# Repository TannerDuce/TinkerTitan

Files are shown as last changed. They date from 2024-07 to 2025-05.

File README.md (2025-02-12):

Tinker Titan V1

New documentation Here --> https://docs.google.com/document/d/1ggTJ-sIj0q-C6EPkmgzcmBBHiNBAO2c4_2ZdBtOWOQ4/edit?tab=t.0

The following set of instructions is outdated, left for reference

Here we will give some basic instructions on how to set up your Tinker Titan, Start to Finish.

**1. Board Assembly:**

Start by soldering the provided connectors onto the main PCB. Depending on how your doing this program, you may also have to
install the surface mount parts yourself, or all of the components will come pre-installed on the circuit board.note that the
2x3 connector in the center of the board is intentionally left blank, as it is the ISP header used to burn the first files
onto the Atmel chip. <-(more on this later)                               .


Next, we solder the motor wires onto the end of the motor. each wire should measure approximately 5.5" long. The wires 
can be cut as short as 5", but a little extra is always good. additionally, tin the opposite ends of the wires. this will 
make it easier to get them into the terminal blocks.
motorwirelength

Next, we will fit the motors into the main chassis. Note that there is a tab on the chassis where the motor lies, which
helps to hold it in place. if the motor is set in upside-down, it simply will not fit in all the way and will need 
to be flipped around. Once the motors are in place, use #4 hardware to secure them, as shown below. Once they are in
place, the cables must be routed along the central channel to provide space for the battery to be set in place on top of them

motorinstalation

Next up is the battery. once you have assembled the battery pack, insert it into the chassis as shown. make sure the
switch on the battery pack is turned on, as it will no longer be accessible. instead of using the switch, the Tinker 
Titan was designed just to be unplugged to power it off.
batterypackinstalation

Once the battery pack is in place, install the cover plate. use #4 hardware to secure it to the chassis.
20240626_125109(0)

Using the machined stand-offs, mount the circuit board to the top of the cover plate as shown below:


Next, wire up your motors into the terminal blocks at the bottom. Don't worry about polarity yet, as long as the 2 wires
from the left motor go to the left terminal block, and the same for the right. (we will correct this later) Try plugging
it in to ensure the battery pack is on. The green light should stay on, solid.



Next, we will assemble the tracks. using the hardware from the back the tracks come in, place the nut in the front slot.
take the short bolt and after placing the wheel on the bolt, add a washer and fasten it to the chassis. for the driven
wheel, find the wheel with the keyed D shaft, and fit it onto the motor. once both are in place, stretch the track over
the two sprockets. do this for both sides of the robot:


Now that the base model is complete, we will add the sensor assembly. this gives the robot the ability to compete in the
sumo challenge and do things such as line following. start by clipping the Ultrasonic sensor into the piece with
the dovetail on it. for this step, make sure that the connector on the ultrasonic sensor faces the opposite way of the 
opening on the dovetail connector. once it is in place, slide the line following module into the remaining piece, and fit
it over the "eyes" of the ultrasonic sensor. 


Once this module is assembled, slide it into the dovetail on the chassis. we use IR#2 for wiring for the line sensor
and the header labelled HC-SR04 for the ultrasonic sensor. As for the line sensor, the pins on the module connect to the 
following pins on the board. OUT --> A6, GND --> GND, and VCC --> 5V. For the Ultrasonic, all the pins' names match
except for power, which on the module is labelled VCC and on the board is noted as 5V. 



**2. Setup Programming:**
You have now completed the hardware assembly, and it is time to move on to the programming! with a fresh board out of the box, 
it will not have a bootloader programmed into it, which is a specific piece of startup code that must be on the chip in order
to be programmed through the USB interface. If you are doing this in class, this section will be completed with the help of the
instructor, but it still doesn't hurt to know what's happening! afterwards, we will continue with ensuring everything else works.

Start by installing the application AVRDUDESS here-> https://github.com/ZakKemble/AVRDUDESS/releases/tag/v2.17 
this application is used to burn the bootloader, which is a term used for adding some code directly onto the microcontroller 
that tells it how to receive code from the USB port. once the application is open, we will set the -b bit clock divider to 16,
(Green box) and then click the detect button (orange box). if done correctly, the board should be recognized and will be confirmed
in the terminal.
Step1program

Second, we will program the fuse bits. note we only want to edit the fuse bit, NOT the lock bit. Copy the values shown in the
picture for the bits shown in the blue box, then the hit Write (red arrow)
Step2program

Finally, we can add in the hex file, and program the boot loader which will be the last step required to be able to use the USB
port for programming. start by downloading the hex file labelled as the hex file for burning the bootloader (in this GitHub repository).
Once it's been loaded in,(orange) select "Write" and then "GO". you have now successfully programmeed the bootloader!
Step3program

**3. Uploading your first program**
here, we will make sure both motors are wired in the correct way, as well as verify that the Line sensor and Ultrasonic work.
Using the Arduino IDE, open the Initializer code, and try uploading it. ensure you have the correct COM port, and that the board
selected is and Arduino UNO. keep it connected to the computer, and open the terminal in the IDE. Once the correct BAUD rate is
selected (9600) you should see a walk-through of what the code will do. if you notice either of the motors are backward, switch
the two wires associated with it around in the terminal block it is connected to. if one motor appears to be stronger than the
other, adjust its weight_value, which is simply a number that the final speed is multiplied by. To set up the line sensor, wave
it over a dar and light patch on paper. if the program cannot tell the difference, try adjusting the potentiometer on the line
sensor. If the line sensor or ultrasonic appear to not be working, ensure all the wires are in the correct spot.

Once it all works, you can go ahead and upload some of the other code provided onto the robot, or try writing some of your own!

And please, by all means if you encounter a problem, go to the issues tab on this github page and report an issue! I will do my best to respond accordingly.

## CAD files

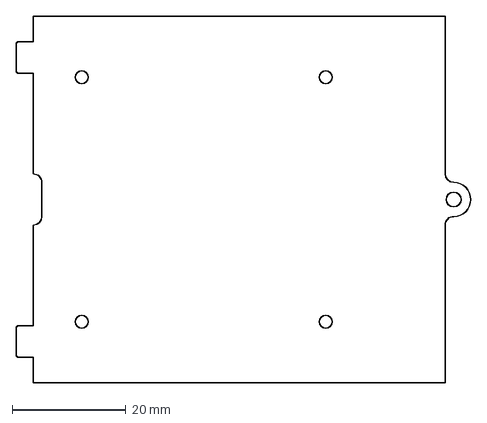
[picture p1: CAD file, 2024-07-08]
Model Files/2d Tinker Titan files/TT-CoverPlate.dxf
80.0 x 64.5 mm

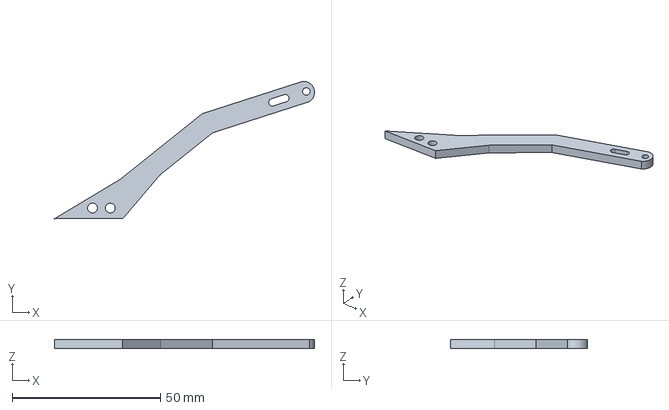
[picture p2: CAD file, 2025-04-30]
Model Files/3d Tinker Titan files/Flipper Arm4.stp
87.6 x 46.3 x 3.17 mm

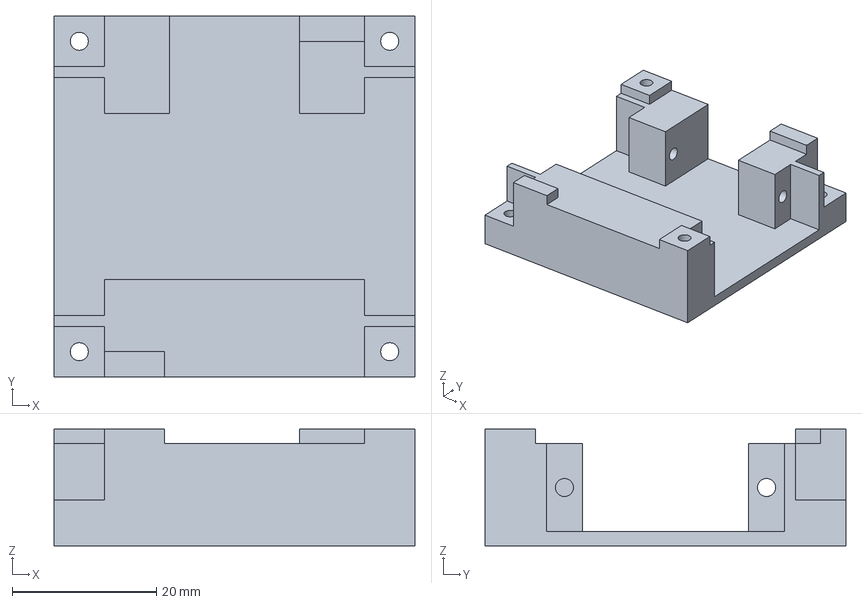
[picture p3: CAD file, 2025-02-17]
Model Files/3d Tinker Titan files/Servo Holder3.stp
50.0 x 50.0 x 16.2 mm

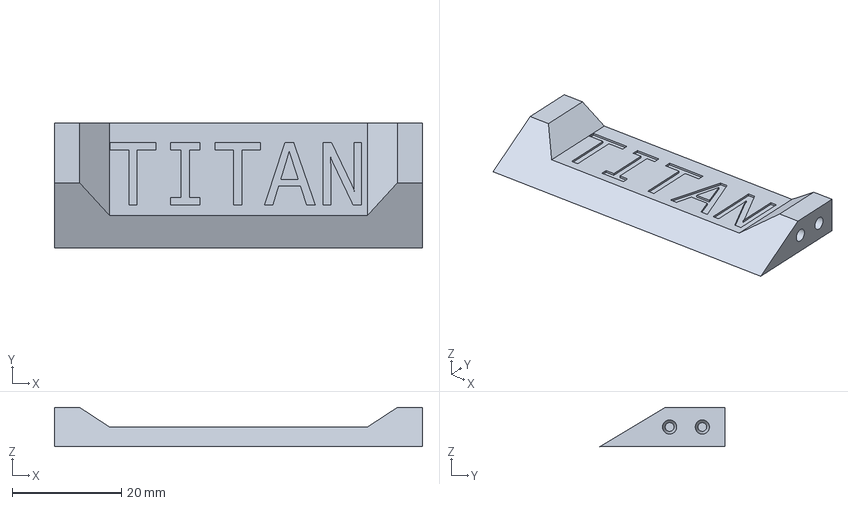
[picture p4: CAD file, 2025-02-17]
Model Files/3d Tinker Titan files/Flipper3.stp
67.5 x 23.0 x 7.20 mm

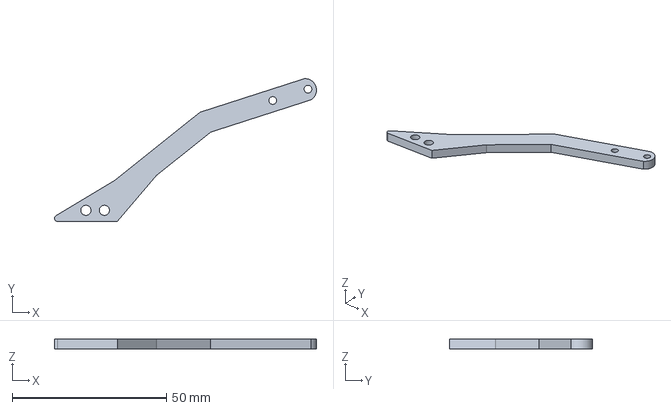
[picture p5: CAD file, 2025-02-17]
Model Files/3d Tinker Titan files/Flipper Arm3.stp
85.0 x 46.3 x 3.17 mm

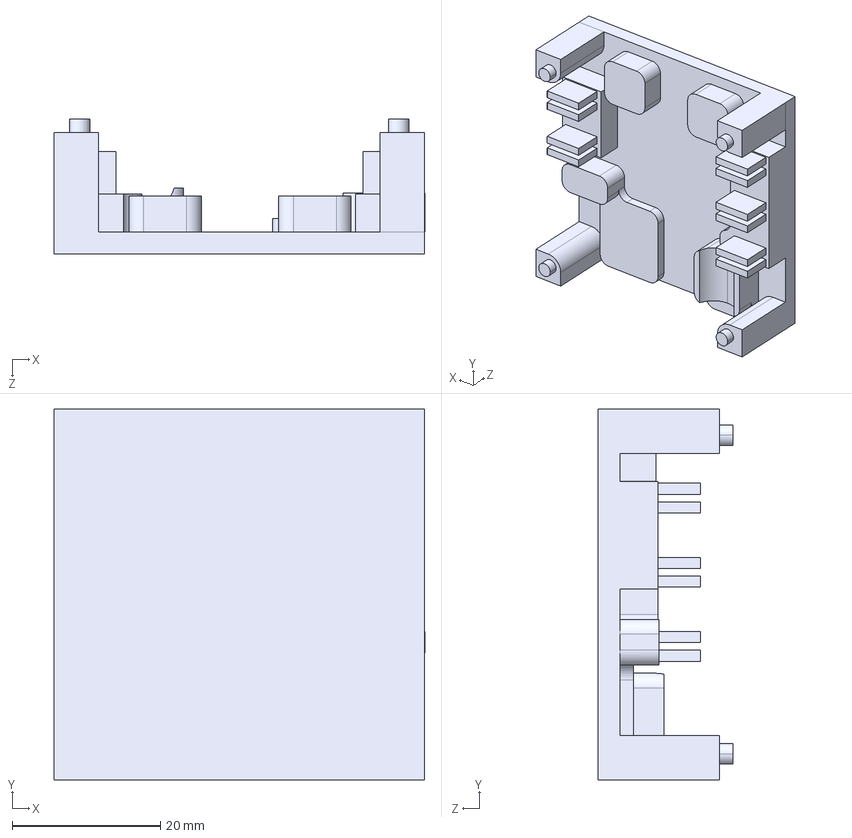
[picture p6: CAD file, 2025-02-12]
Model Files/3d Tinker Titan files/Tinker Titan Solder Jig.STEP
50.0 x 50.0 x 18.2 mm

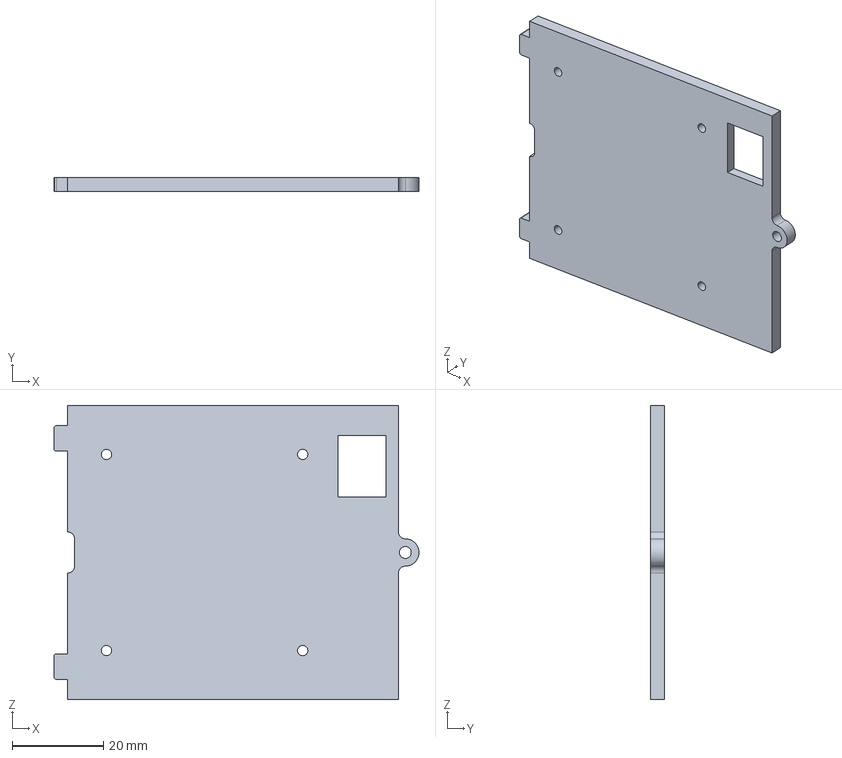
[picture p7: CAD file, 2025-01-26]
Model Files/3d Tinker Titan files/TT-CoverPlate Power Slot.stp
80.0 x 3.18 x 64.5 mm

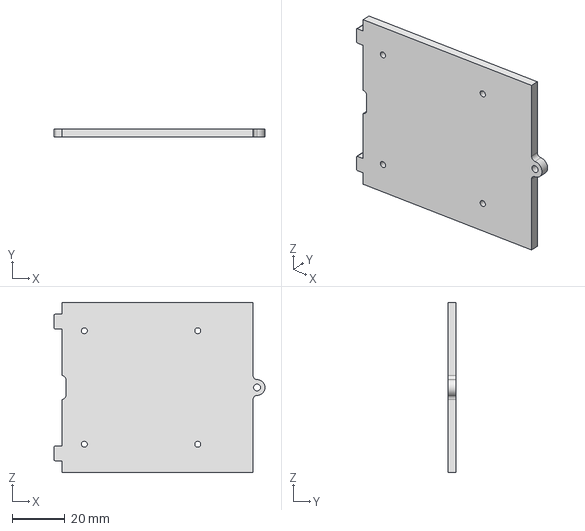
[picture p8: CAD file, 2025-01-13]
Model Files/3d Tinker Titan files/TT-CoverPlate.stp
80.0 x 3.18 x 64.5 mm

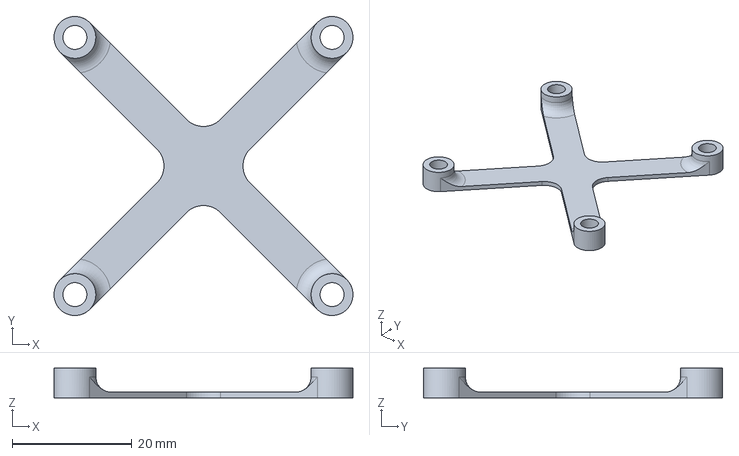
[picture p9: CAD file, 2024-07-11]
Model Files/3d Tinker Titan files/Plastic_standoff.stp
50.0 x 50.0 x 5.00 mm

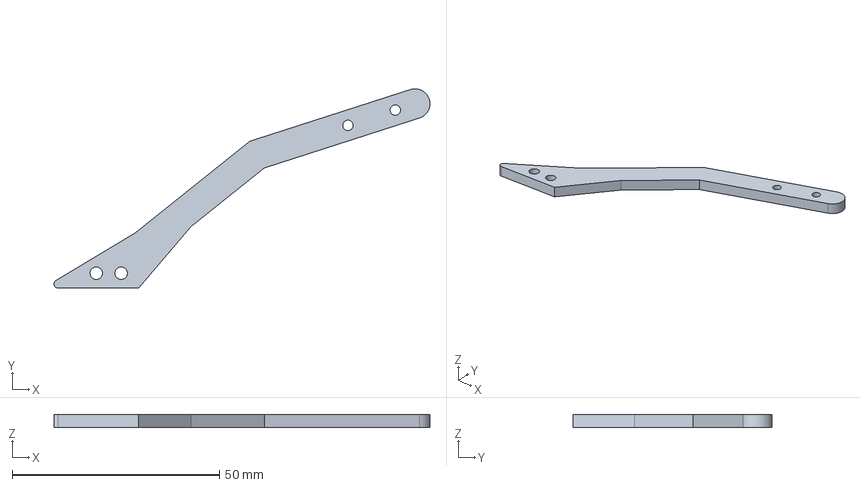
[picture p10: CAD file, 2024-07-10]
Model Files/3d Tinker Titan files/Flipper2.stp
90.6 x 48.0 x 3.17 mm

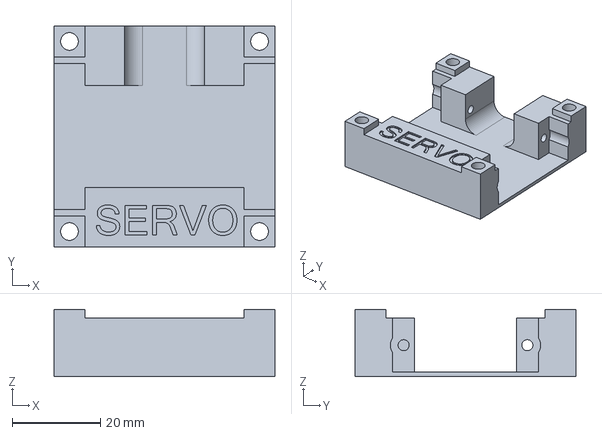
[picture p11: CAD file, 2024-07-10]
Model Files/3d Tinker Titan files/Servo Holder.stp
50.0 x 50.0 x 15.2 mm

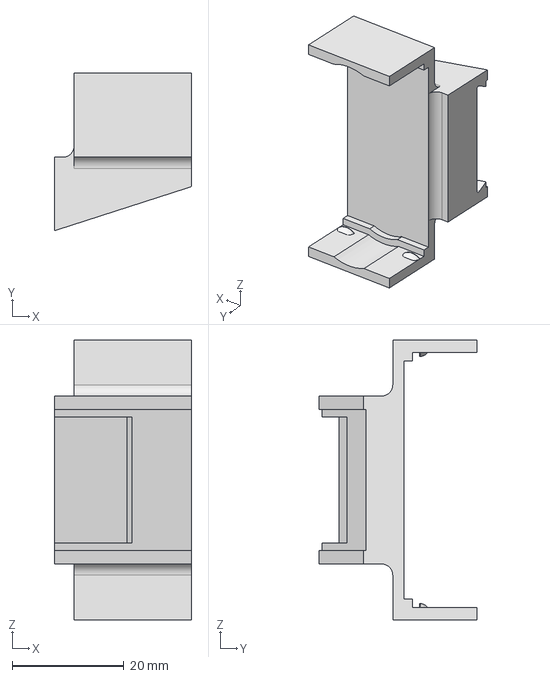
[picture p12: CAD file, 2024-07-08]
Model Files/3d Tinker Titan files/SensorHolderBracketPT2.stp
24.5 x 28.1 x 50.0 mm

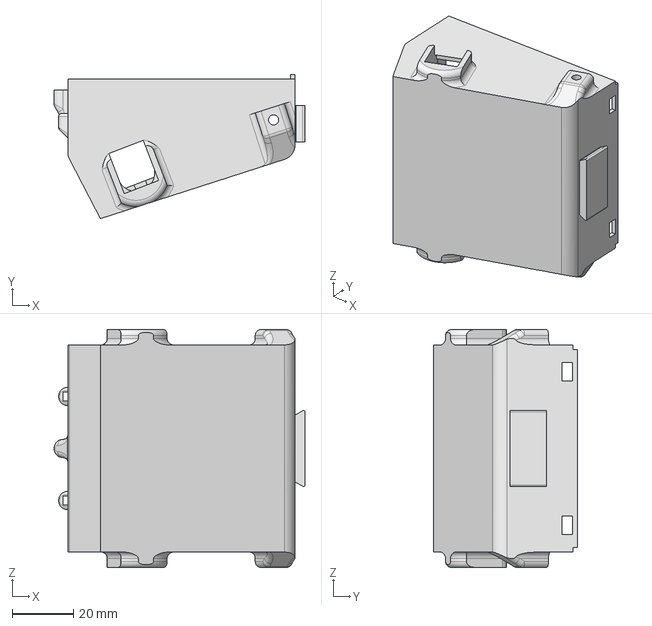
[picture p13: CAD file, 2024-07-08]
Model Files/3d Tinker Titan files/TTChassisV1.stp
81.7 x 47.0 x 77.5 mm

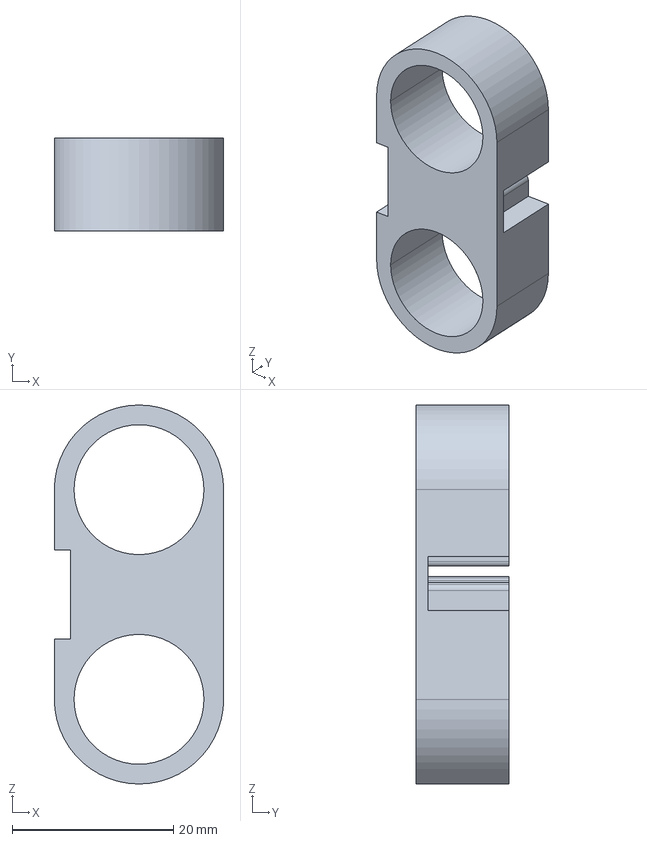
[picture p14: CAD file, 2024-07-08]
Model Files/3d Tinker Titan files/SensorHolderBracketv2.stp
21.0 x 11.5 x 47.0 mm

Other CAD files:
Model Files/3d Tinker Titan files/TT-CoverPlate Power Slot No chamfer.stp
Model Files/3d Tinker Titan files/Servo_HolderV2.stp
Model Files/3d Tinker Titan files/Flipper.stp

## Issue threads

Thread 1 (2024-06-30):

Possible changes to make to 3D design

TannerDuce, 2024-06-30:
Extend the dovetail connector to the build platform to remove support
Increase tolerance for Ultrasonic sensor to fit in the holder better
Add more space in the channel for the motor wires

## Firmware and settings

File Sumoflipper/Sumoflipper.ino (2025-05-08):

#include <Ultrasonic.h>

#include <Servo.h>
#define right_servo_pin 10
#define left_servo_pin 9
Servo myservoright;
Servo myservoleft;


//each motor is controled by two pins,(plus an enable pin) and depening on what combination of values
//you set the pins to you can get it to move in the desired direction
#define left_motor_sleep 16
#define left_motor_a 5
#define left_motor_b 6
#define left_motor_weight 1 //the final value sent to the motor will be multipled by this. set it between -1 and 1
//weight is usefull for tweeking un-ballenced motors, incase one is naturaly faster than the other. this feature is also handy
//if you discover your motors are backwards. simply make the value negitive
#define right_motor_sleep 2
#define right_motor_a 3
#define right_motor_b 11
#define right_motor_weight 1 //the final value sent to the motor will be multipled by this. set it between 0 and 1
//===========code varibles===========
Ultrasonic ultrasonic(A1, A0);
int distance;
int SUMOSTATE = 0;

//===========================================USER VARIBLES==================================================
#define trigger_distance 50 // distance(cm) before robot will trigger. set this to the ring diametre for best results
#define grace_period 5000 //the number in (ms) before the robot will begin searching for other bots.

void setup() {
  // put your setup code here, to run once:
  Serial.begin(9600);
  Serial.println("Initializing");
  pinMode(left_motor_sleep, OUTPUT);
  pinMode(left_motor_a, OUTPUT);
  pinMode(left_motor_b, OUTPUT);
  pinMode(right_motor_sleep, OUTPUT);
  pinMode(right_motor_a, OUTPUT);
  pinMode(right_motor_b, OUTPUT);

  //turn on the motor drivers
  digitalWrite(left_motor_sleep, HIGH);
  digitalWrite(right_motor_sleep, HIGH);
  myservoleft.attach(left_servo_pin);
  myservoright.attach(right_servo_pin);
  pinMode(right_servo_pin, OUTPUT);
  pinMode(left_servo_pin, OUTPUT);
  //after initializing everything, wait for the grace period to end. this gives time to plug in the robot,
  //and get it properly positioned in the circle before the match begins
  delay(grace_period);
  myservoleft.write(90);//Bucket down pos
  myservoright.write(90);




}

void loop() {
  // put your main code here, to run repeatedly:
  //We are going to run a state machine here. We start the program in state 0.
  //STATE ZERO CONDIDIONS:
  //    We are in state ZERO, meaning we have succsessfuly pushed someone out of the ring, or we have just started the program
  //    here, we check for if,
  //    A, The color sensor does not see the outer ring line AND
  //    B, The ultrasonic sensor does not see a value less than (trigger_distance). <-- make this the diameter of the ring
  //    if A becomes false, enter state ONE
  //    if B becomes false, enter state TWO
  //    if both remain true, we continue slowly rotating right in search of an opponent
  //STATE ONE CONDITIONS
  //    We have entered state one, meaning we are on the line. We proceed by backing up the robot and turning around.
  //    after this, we return to state ZERO
  //STATE TWO CONDITIONS
  //    we have entered state TWO, meaning an opponent has been located, and now we must attempt to push them out of the circle.
  //    We start by calling a Drive(9,9), and then check the line sensor
  //    The only way to leave this state is if a line is seen. theirfore in this state,
  //    we check the line sensor every loop. if the line sensor is triggered, we enter STATE ONE
  distance = ultrasonic.read();
  Serial.println(distance);
  Serial.print("state of machine is...");
  Serial.println(SUMOSTATE);
  delay(30); //this shouldnt be here, but the ultrasonic cant keep up, so it is
  if(SUMOSTATE == 0)
  {
    if((analogRead(6))>500)   //use < if the ring is black with a white line and > for white with a black line (do to line 149 aswell)
    {
      //if this code runs, that means we have seen a line!
      SUMOSTATE = 1;
    }

    else if(distance < trigger_distance)
    {
      if(distance != 0)
      {
        //if this code runs, that means we have seen a robot!
        Serial.println("ultrisonic trigger");
        SUMOSTATE = 2;
        delay(100);
      }
    
      //if this code runs, that means we have seen a robot!
      // Serial.println("ultrisonic trigger");
      // SUMOSTATE = 2;
    }

    else
    {
      //neither exit condition was met, so we slowly turn to the left and keep searching
      drive(6,-6);
    }

  }

  else if(SUMOSTATE == 1)
  {
    //we have seen a line. back up and turn around:
    drive(5,5);
    delay(1000);
    drive(6,-6);
    delay(500);
    coast();
    SUMOSTATE = 0;

  }

  else if(SUMOSTATE == 2)
  {
    //we see a robot, time to push it out of the circle!
    drive(-9,-9);
    if(distance>333 || distance<5)
    {
      
        Serial.println("welp, im here");
        myservoleft.write(0);//Bucket up pos
        myservoright.write(180);
        if((analogRead(6))>500)
        {
          // after setting the motors to almost full speed, we continuiosly check if we have seen the line. if so,
          applyBrake();
          SUMOSTATE = 1;
        }
        delay(200);
        myservoleft.write(90);//Bucket down pos
        myservoright.write(90);
        delay(40);
      
    }
    if((analogRead(6))>500)
    {
      // after setting the motors to almost full speed, we continuiosly check if we have seen the line. if so,
      applyBrake();
      SUMOSTATE = 1;
    }

  }

}

//===========================================================FUNCTIONS============================================================
void drive(int left_track_speed,int right_track_speed)
{
  //drive Forwards by setting a=1 and b=0. to get different speeds, we PWM one of the pins.
  //The parameters passed in have a value from -10 to 10, of which negitive speeds will drive backwards.
  //Motors will contuniously spin untill either the applyBrake() or coast() functions are called.

  //code for left motor:
  if(left_track_speed>0)
  {
  digitalWrite(left_motor_a, LOW);
  analogWrite(left_motor_b, round(left_track_speed*25*left_motor_weight));
  }
  else
  {
    analogWrite(left_motor_a, round(left_track_speed*(-25)*left_motor_weight));
    digitalWrite(left_motor_b, LOW);
  }

  //code for right motor:
  if(right_track_speed>0)
  {
  digitalWrite(right_motor_a, LOW);
  analogWrite(right_motor_b, round(right_track_speed*25*right_motor_weight));
  }
  else
  {
    analogWrite(right_motor_a, round(right_track_speed*(-25)*right_motor_weight));
    digitalWrite(right_motor_b, LOW);
  }

}


void applyBrake()
{
  //sets both bits high, which electricaly connects the motor to itself so that
  //when a rotational force is applied, the motor creates an opposing force acting as brakes
  digitalWrite(left_motor_a, HIGH);
  digitalWrite(left_motor_b, HIGH);
  digitalWrite(right_motor_a, HIGH);
  digitalWrite(right_motor_b, HIGH);
}

void coast()
{
  //sets both pins low, leaving the motor to stop spinning on its own
  digitalWrite(right_motor_a, LOW);
  digitalWrite(right_motor_b, LOW);
  digitalWrite(left_motor_a, LOW);
  digitalWrite(left_motor_b, LOW);
}

void smash()
{
  delay(100);
  drive(-8,-8);
  delay(1500);
  drive(8,8);
  delay(1500);
}

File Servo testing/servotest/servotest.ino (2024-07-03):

#include <Servo.h>
#define right_servo_pin 10
#define left_servo_pin 9
Servo myservoright;
Servo myservoleft;


void setup() {
  
myservoleft.attach(left_servo_pin);
myservoright.attach(right_servo_pin);

  // put your setup code here, to run once:
  pinMode(right_servo_pin, OUTPUT);
  pinMode(left_servo_pin, OUTPUT);

}

void loop() {
  // put your main code here, to run repeatedly:
  myservoleft.write(5);//Bucket down pos
  myservoright.write(170);
  delay(1000);
  myservoleft.write(47);//Bucket up pos
  myservoright.write(120);
  delay(1000);
  // delay(1000);
  // myservoleft.write(100);
  // myservoright.write(180-100);
  // delay(1000);

}


// void Setservo(int angle)
// {

//   myservoleft.write(angle);
//   myservoright.write(180-angle);
// }

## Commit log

2024-07-03 added support for sumo with servos
2024-07-08 Added 3D files
    [SensorHolderBracketPT2.stp, SensorHolderBracketv2.stp, TT-CoverPlate.dxf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]
2024-07-10 added sumo flipper models
    [Flipper2.stp, Servo Holder.stp]
2024-07-10 added sumo flipper file
    [Flipper.stp]
2024-07-11 added remaining 3d files
    [Plastic_standoff.stp, Servo_HolderV2.stp]
2024-07-12 updated sumo with flipper code
    [Sumoflipper.ino]
2024-07-12 update sumo with flipper code
    [Sumoflipper.ino]
2025-01-13 Add files via upload
    Added step file for Laser Cut plate
    [TT-CoverPlate.stp]
2025-01-13 added coverplate
    [TT-CoverPlate.stp]
2025-01-26 added new cover plate design
    [TT-CoverPlate Power Slot No chamfer.stp]
2025-02-12 added soldering jig files
    [Tinker Titan Solder Jig.STEP]
2025-02-17 added v3 flipper arm
    [Flipper Arm3.stp]
2025-02-17 added v3 flipper
    [Flipper3.stp]
2025-02-17 added v3 servo holder
    [Servo Holder3.stp]
2025-04-30 added slot to flipper arm 4
    [Flipper Arm4.stp]
2025-05-08 update sumo flipper with different colours on ring edge
    [Sumoflipper.ino]
